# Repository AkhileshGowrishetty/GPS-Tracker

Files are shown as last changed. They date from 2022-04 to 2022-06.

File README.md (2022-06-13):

# GPS Tracker Project

A GPS Tracker Prototype used for locating tracking vehicles.

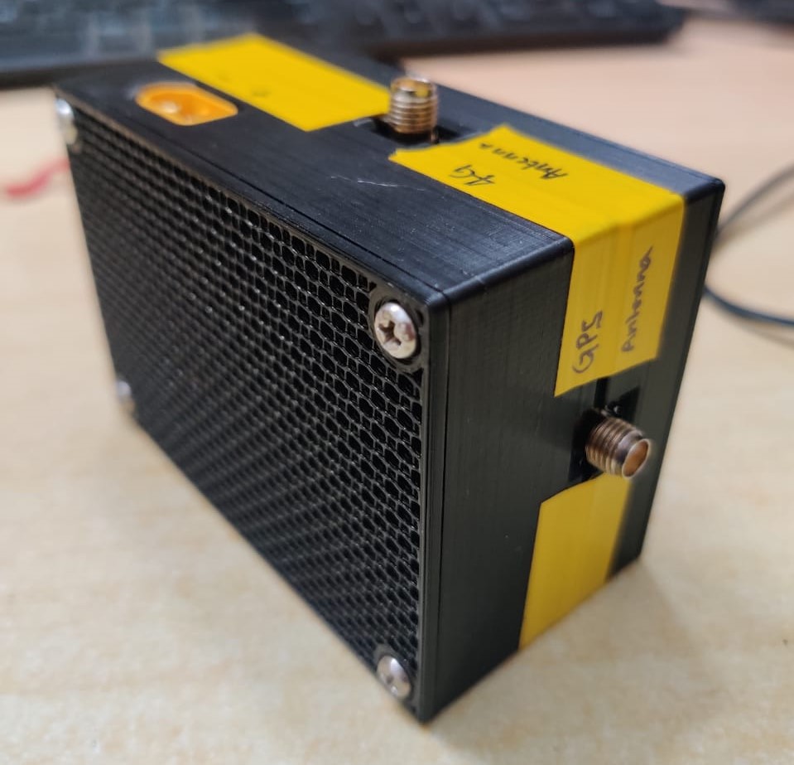
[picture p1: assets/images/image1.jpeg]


**Hardware:**
1. ESP32
1. SIM7600EI

The SIM7600 module used in this project can be at rhydoLABZ. The PCB and 3D designed enclosure are specific to this module.

This tracker gets the current location coordinates using the SIM7600 module, and then sends them to AWS. A web site is hosted on AWS to display the coordinates from the tracker.

AWS IoT Core, DynamoDB and EC2 services from AWS are used for this project.

---

### Instructions:
- The file `secrets_template.h` has the variables that has to be edited. After editing, rename the file to `secrets.h` and place it in the same folder that has the `main.cpp` file.
    ```
    The folder structure has to be some thing like this:
    -- Project
        | -- 
        | -- 
        | -- src
            | -- secrets.h
            | -- main.cpp
            | -- SIM7600.cpp
            | -- SIM7600.h
        | -- 
    ```

- Follow the steps in [Documentation for AWS](./Documentation/AWS_IoT_Core_Documentation.md) and [Documentation for SIM7600](./Documentation/Setting_Up_SIM7600.md).
    > For deeper understanding of the AT Commands, the document "SIM7500_SIM7600 Series_ AT Command Manual" can be referred.

- This project was developed in [PlatformIO](https://platformio.org/). There are many tutorials which help in installing and uploading the program to the ESP32.

---
### Understanding the code:
- The code creates few tasks to control various peripherals. 
    1. LED control
    1. Battery monitoring system
    1. Active time management
    1. Fetch GPS co-ordinates and Publish to AWS
    1. Monitoring the Serial input. (Work in progress)

- A semaphore is used to control the number of the times the status LED blinks. Few FreeRTOS functions to handle tasks are used to suspend and resume the LED control task.

- To prevent the battery from discharging through the voltage divider used for voltage level detection, a MOSFET is used to enable the voltage divider. This task also switched OFF the SIM7600 module if the voltage is low.

---
### Troubleshooting:
- To disable MQTT functions, the line `#define MQTT_CONNECT` can be commented. By commenting it, the AT commands corresponding to MQTT connection, publishing are not sent to SIM7600 module.

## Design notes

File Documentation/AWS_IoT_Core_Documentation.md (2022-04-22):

# AWS IoT Core Wiki

Documentation for the AWS IoT implemetation in Tracker project.

> References:  
> 1. [AWS Compute Blog - Building an AWS IoT Core device using AWS Serverless and an ESP32](https://aws.amazon.com/blogs/compute/building-an-aws-iot-core-device-using-aws-serverless-and-an-esp32/)
> 1. [AWS Docs - Tutorial: Storing device data in a DynamoDB table](https://docs.aws.amazon.com/iot/latest/developerguide/iot-ddb-rule.html)
---

**Table of Contents**

1. [Setting up IoT Core](#1-setting-up-iot-core)
    1. Registering a New Thing
    1. Creating a Policy
    1. Attaching the Policy
1. [Setting up Rule to insert received Data to DynamoDB](#2-setting-up-rule-to-insert-received-data-to-dynamodb)
    1. Creating a New Rule and Setting up Actions in the Rule

---

## 1. Setting up IoT Core
1. Registering a New Thing:  
    -  In the AWS Console, a Thing has to be registered before connecting to the MQTT broker. Firstly, we have to create in New Thing. Choose 'Things' in the console and choose **Register a New Thing**. Create a single thing.  
    - The thing can be named anything. The remaining fields can be left empty. Click on **Next**.  
    - Choose **Create Certificate**. Make sure to Download the *thing cert*, *private key* and *Amazon Root CA1* certificates. Save them somewhere secure. They will be needed to connect to the AWS IoT.
        > In this project, these certificates are sent to SIM7600 Module. The instructions can be found [here](./Setting_Up_SIM7600.md#2-download-certificates).
    - Click on **Activate**, **Attach a policy**.  
        > A policy is an object in AWS that, when associated with an identity or resource, defines their permissions. - [AWS Docs](https://docs.aws.amazon.com/IAM/latest/UserGuide/access_policies.html)
    - Skip adding a policy as of now. 
    - Choose **Register Thing**.

1. Creating a Policy:
    - In the AWS Console, choose **Secure, Policies, Create a policy**.
    - Name the policy. Choose the **Advanced** tab.
    - The following policy template can be pasted. In the template, replace the following:
        - **REGION:ACCOUNT_ID** with your **AWS region** and **AWS Account ID**.    
        - **ThingName** with the name of the Thing that was registered in previous step.
        - **SubTopic** with the topic which the Thing can subscribe.
        - **PubTopic** with the topic which the Thing can publish to.  
        ```json
        {
            "Version": "2012-10-17",
            "Statement": [
                {
                "Effect": "Allow",
                "Action": "iot:Connect",
                "Resource": "arn:aws:iot:REGION:ACCOUNT_ID:client/ThingName"
                },
                {
                "Effect": "Allow",
                "Action": "iot:Subscribe",
                "Resource": "arn:aws:iot:REGION:ACCOUNT_ID:topicfilter/SubTopic"
                },
                {
                "Effect": "Allow",
                "Action": "iot:Receive",
                "Resource": "arn:aws:iot:REGION:ACCOUNT_ID:topic/SubTopic"
                },
                {
                "Effect": "Allow",
                "Action": "iot:Publish",
                "Resource": "arn:aws:iot:REGION:ACCOUNT_ID:topic/PubTopic"
                }
            ]
        }
        ```
    - Choose **Create**.

1. Attaching the Policy:
    - In the AWS Console, choose **Secure, Certification**.
    - Select the one that was created for the registered device and choose **Actions, Attach Policy**.
    - Choose the previously created policy and click on **Attach**.

---

## 2. Setting up Rule to insert received Data to DynamoDB
Prior to Rule creation, a Table in DynamoDB must be created. It will have a primary key, sort key and data as columns. For this example, it is expected that a Table has a primary key of *Number* type and sort key of *String* type. The primary key will store the **Timestamp** and the sort key will store the **Topic** of the MQTT message.  
### Creating a New Rule and Setting up Actions in the Rule:  
- In the AWS Console, choose **Act, Rules**.
    - Click on **Create**.
    - In the top part of **Create a rule**:
        - In **Name**, enter the rule's name.
        - The rule can be described in the **Description**.
    - In the **Rule query statement** of **Create a rule**:
        - Select `2016-03-23` in **Using SQL version**.
        - In the **Rule query statement** edit box, paste the following. The statement implies that all the data from the topic to which data is published (**PubTopic**) is selected.
            ```sql
            SELECT * FROM "PubTopic"
            ```
    - In **Set one or more actions**:
        - Choose **Add action**, to open a list of rule actions.
        - In **Select an action**, choose **Insert a message into a DynamoDB table**.
        - Choose **Configure action** to open the selected action's configuration page.
    - In **Configure action**:
        - Choose the name of the DynamoDB Table to use in **Table Name**.
        - In **Partition key value**, enter `${timestamp()}`.
        - In **Sort key value**, enter `${topic()}`.
        - In **Write message data to this column**, enter `device_data`. This will create the `device_data` column in the DynamoDB Table.
        - The **Operation** field can be left blank.
        - In **Choose or create a role to grant AWS IoT access to perform this action**, choose **Create Role** if a new role has to be created or choose and existing role with the policies that allows to put an item in DynamoDB Tables.
        - In **Create a new role** enter the name of the role, and choose **Create role**.
        - Choose **Add action** at the bottom of **Configure action**.
        - Choose **Create rule** at the bottom of **Create a rule** to create the rule.

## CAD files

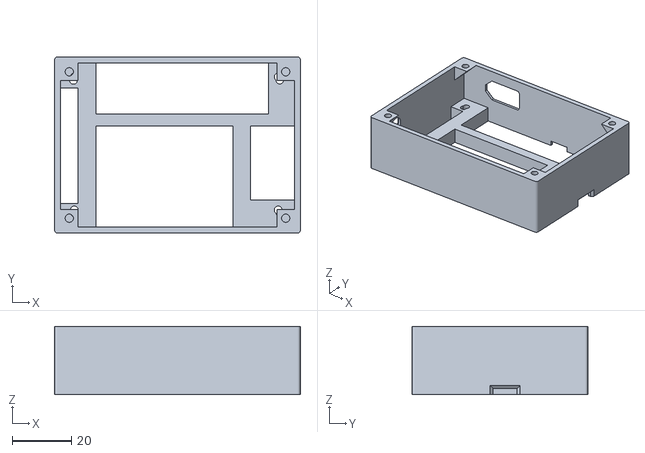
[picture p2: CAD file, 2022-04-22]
Enclosure/Holder_PCB.stl
83.0 x 59.4 x 23.0

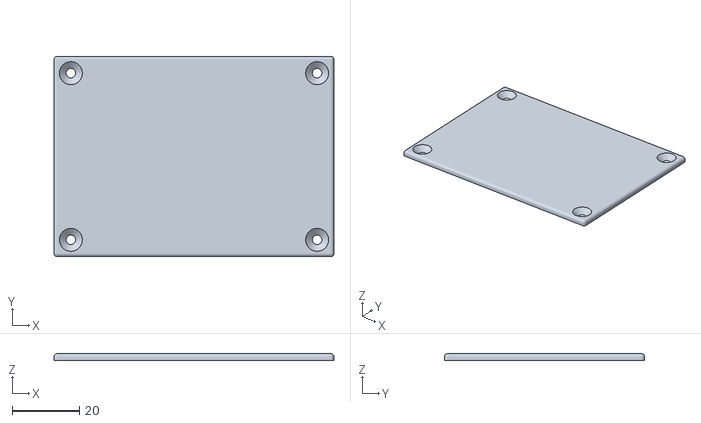
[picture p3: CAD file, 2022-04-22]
Enclosure/Cover_PCB.stl
83.0 x 59.4 x 2.00

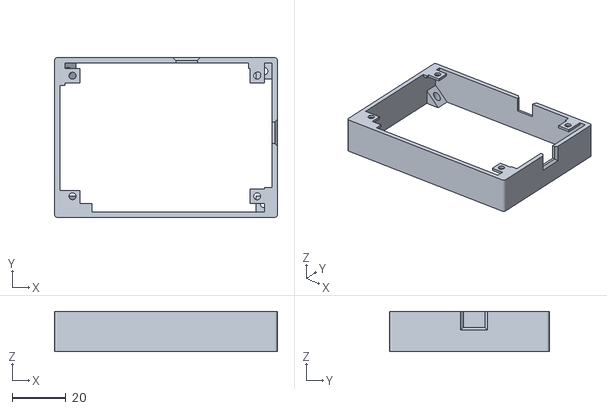
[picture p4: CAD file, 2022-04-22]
Enclosure/Holder_SIM7600.stl
83.0 x 59.4 x 15.0

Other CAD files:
Enclosure/Cover_SIM7600.stl

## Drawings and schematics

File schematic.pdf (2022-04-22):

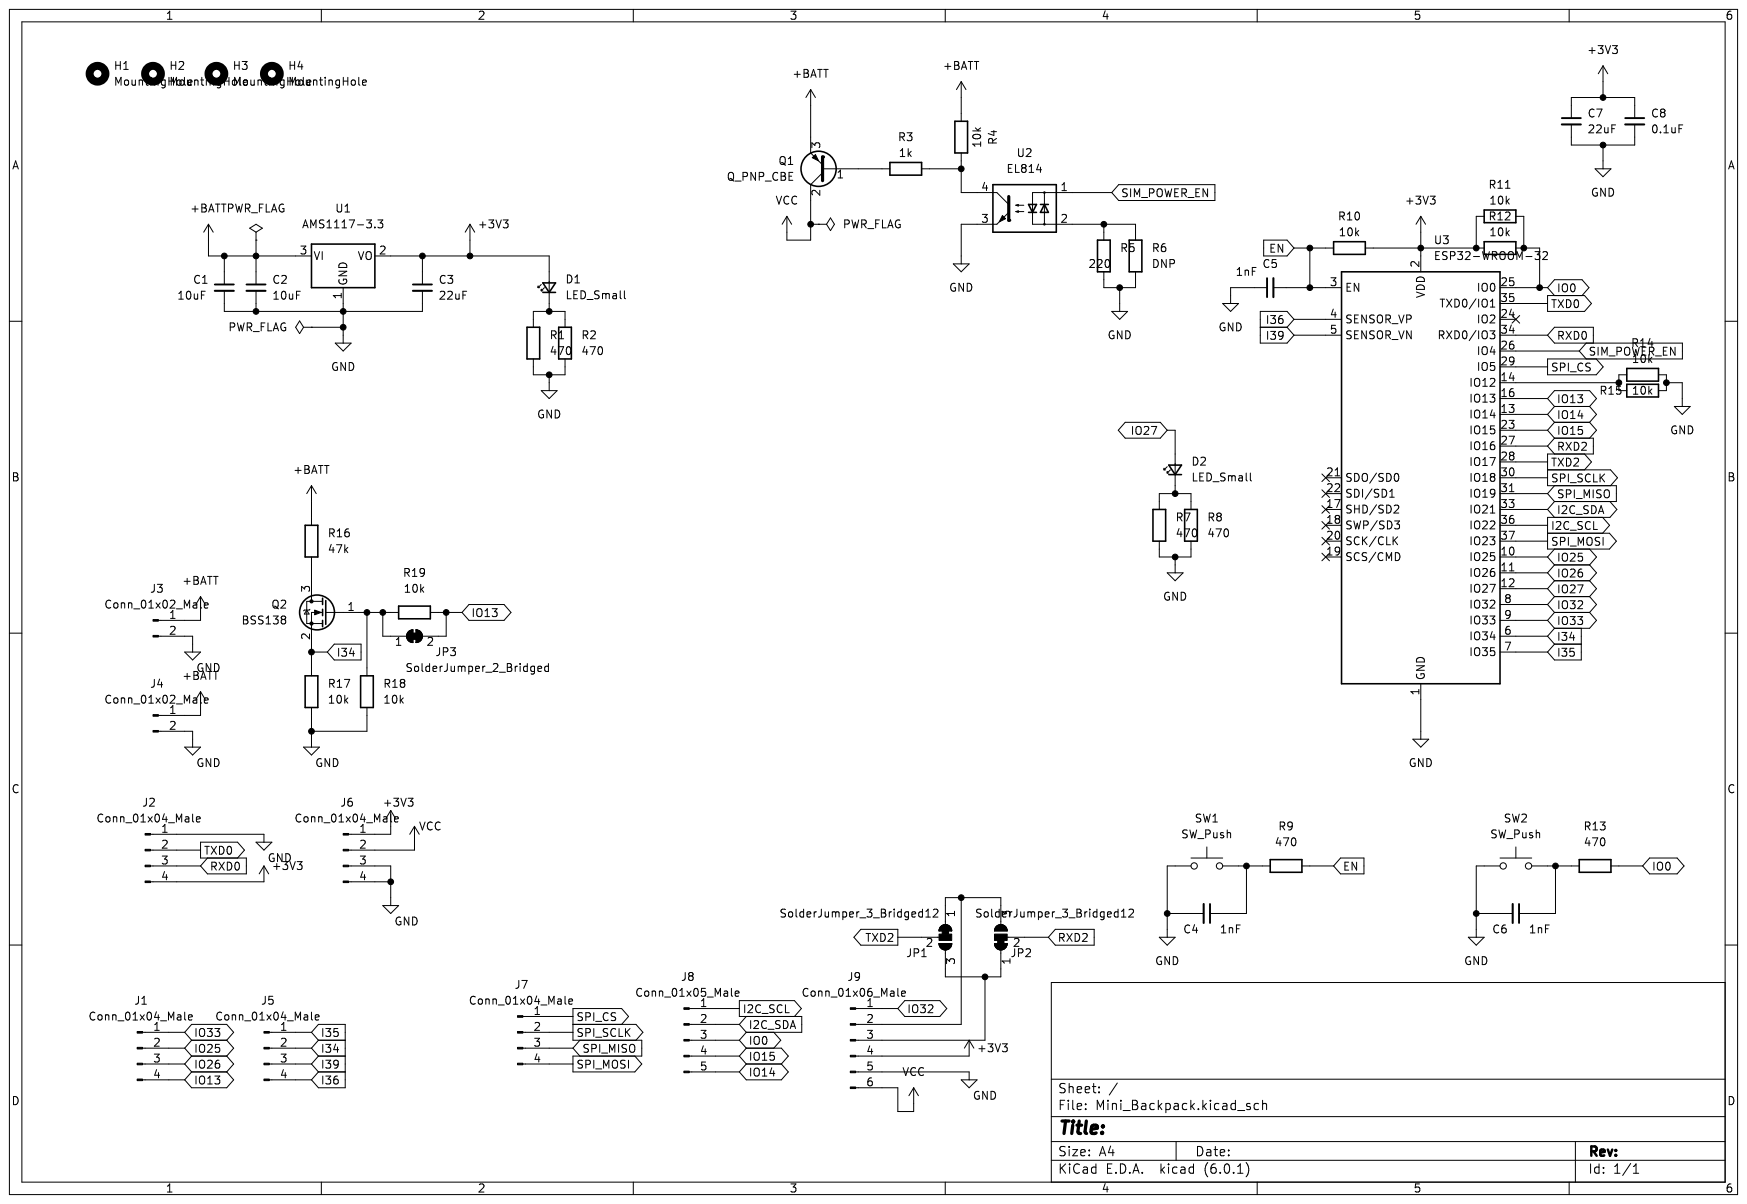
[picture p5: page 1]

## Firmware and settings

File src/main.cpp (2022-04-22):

#include <Arduino.h>
#include "SIM7600.h"
#include "secrets.h"
#include "functions.h"


void setup()
{
	Serial.begin(115200);
	Serial2.begin(115200);

	xSemaphoreGive(Semaphore_LED_blink_count);

	xTaskCreatePinnedToCore(blink_LED, "LED Blink", 2048, NULL, 1, &Task_LED_Control, 1);
	xTaskCreatePinnedToCore(battery_monitor, "Battery Monitoring Function", 2048, NULL, 1, &Task_Battery_Monitor, 1);
	
	
	
	delay(10000);
	sim7600.waitForResponse("PB DONE", 25);

	sim7600.echoOFF() ? ESP_LOGI(SIM7600_TAG, "Echo switched OFF") : ESP_LOGE(SIM7600_TAG, "Echo did not switch OFF");

	configureSSL_MQTT();

	gps.begin();

	xTaskCreatePinnedToCore(update_active_hours, "Real Time Management", 2048, NULL, 1, &Task_Clock, 1);
	xTaskCreatePinnedToCore(fetchGPS_pubMQTT, "Fetch GPS and Publish MQTT", 4096, NULL, 1, &Task_fetchGPS_pubMQTT, 1);
	//xTaskCreatePinnedToCore(serial_monitor, "Monitor Output from SIM7600", 4096, NULL, 1, &Task_Serial, 1);
}

void loop()
{

}

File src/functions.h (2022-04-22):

#ifndef FUNCTIONS_H
#define FUNCTIONS_H

#include "Arduino.h"
#include "SIM7600.h"
#include "driver/adc.h"
#include "esp_adc_cal.h"
#include "secrets.h"

#define MQTT_CONNECT
#define DEVICE_TAG "GPS Tracker Prototype"
#define SIM7600_TAG "SIM7600"
#define SSL_TAG "SSL"
#define MQTT_TAG "MQTT"

SIM7600 sim7600(Serial2);
GPS gps(Serial2);
MQTT mqtt(Serial2);
SSL ssl(Serial2);

TaskHandle_t Task_fetchGPS_pubMQTT;

TaskHandle_t Task_LED_Control;

TaskHandle_t Task_Battery_Monitor;

TaskHandle_t Task_Serial;

TaskHandle_t Task_Clock;

SemaphoreHandle_t Semaphore_LED_blink_count = xSemaphoreCreateBinary();

gpio_num_t LED = GPIO_NUM_27;
gpio_num_t BATTERY_MONITOR_EN = GPIO_NUM_13;

const double slope = 5.70;
const double BATT_min = 6.00;

const unsigned int AWS_update_interval_ms = 5000;

bool active_hours = true;
const unsigned int aws_port = 8883;
uint8_t LED_blink_count = 1;

/**
 * @brief Function to calculate the battery voltage using the voltage divider with MOSFET. 12-bit resolution.
 * 
 * 
 * @return double - Voltage of battery.
 */
double battery_voltage()
{
	gpio_set_level(BATTERY_MONITOR_EN, 1);
	vTaskDelay(50 / portTICK_PERIOD_MS);

	esp_adc_cal_characteristics_t adc_chars;

	esp_adc_cal_characterize(ADC_UNIT_1, ADC_ATTEN_DB_6, ADC_WIDTH_BIT_12, 1100, &adc_chars);

	uint32_t voltage;
	esp_adc_cal_get_voltage(ADC_CHANNEL_6, &adc_chars, &voltage);

	gpio_set_level(BATTERY_MONITOR_EN, 0);
	return (slope * (voltage / 1000.0) ) + 0.075;
}

/**
 * @brief Function to end the MQTT session.
 * 
 */
void endMQTT()
{
	#ifdef MQTT_CONNECT
	mqtt.disconnect() ? ESP_LOGI(MQTT_TAG, "MQTT broker disconnected") : ESP_LOGE(MQTT_TAG, "MQTT broker disconnection failed.");
	mqtt.releaseClient() ? ESP_LOGI(MQTT_TAG, "MQTT client released") : ESP_LOGE(MQTT_TAG, "MQTT client not released");
	mqtt.end() ? ESP_LOGI(MQTT_TAG, "MQTT session ended successfully") : ESP_LOGE(MQTT_TAG, "MQTT session did not end");
	#endif
}

/**
 * @brief Update the active_hours boolean based on the current time and active time.
 * 
 * @todo Implementation
 * 
 * @param parameter 
 */
void update_active_hours(void * parameter)
{
	while(true)
	{
		vTaskDelay(1000 / portTICK_PERIOD_MS);
	}
}

/**
 * @brief Task to monitor the battery voltage and switch ON/OFF the SIM module.
 * 
 * @param parameter 
 */
void battery_monitor(void * parameter)
{
	gpio_reset_pin(BATTERY_MONITOR_EN);
	gpio_set_direction(BATTERY_MONITOR_EN, GPIO_MODE_OUTPUT);

	adc_set_clk_div(1);
	adc1_config_width(ADC_WIDTH_BIT_12);
	adc1_config_channel_atten(ADC1_CHANNEL_6, ADC_ATTEN_DB_6);

	while(true)
	{
		if ( battery_voltage() < BATT_min + 0.3 || !active_hours)
		{
			vTaskSuspendAll();
			endMQTT();
			sim7600.shutdown();
			vTaskDelay(200 / portTICK_PERIOD_MS);
			sim7600.powerOFF();
			xSemaphoreTake(Semaphore_LED_blink_count, portMAX_DELAY);
			LED_blink_count = 3;
			xSemaphoreGive(Semaphore_LED_blink_count);

			while(true)
			{
				if ( !active_hours )
					vTaskResume(Task_LED_Control);
				vTaskDelay(2000 / portTICK_PERIOD_MS);
			}
		}
		else
		{
			sim7600.powerON();
		}
		vTaskDelay(5000 / portTICK_PERIOD_MS);
	}
}

/**
 * @brief Task to blink the LED based on the count.
 * 
 * @param parameter 
 */
void blink_LED(void *parameter)
{	
	gpio_reset_pin(LED);
	gpio_set_direction(LED, GPIO_MODE_OUTPUT);

	uint8_t blink_count;

	while (true)
	{
		gpio_set_level(LED, 0);
		vTaskSuspend(NULL);
		
		xSemaphoreTake(Semaphore_LED_blink_count, portMAX_DELAY);
		blink_count = LED_blink_count;
		xSemaphoreGive(Semaphore_LED_blink_count);

		for (uint8_t i = 0; i < blink_count; i++)
		{
			gpio_set_level(LED, 1);
			vTaskDelay(100 / portTICK_PERIOD_MS);
			gpio_set_level(LED, 0);
			vTaskDelay(100 / portTICK_PERIOD_MS);
		}
	}
}

/**
 * @brief Function to configure the SSL context and connect to the AWS MQTT broker.
 * 
 */
void configureSSL_MQTT()
{
	#ifdef MQTT_CONNECT
	ssl.checkCertificates(cacert, clientcert, clientkey) ? ESP_LOGI(SSL_TAG, "Certificates present") : ESP_LOGE(SSL_TAG, "Certificates not found");
	ssl.configureSSL(cacert, clientcert, clientkey) ? ESP_LOGI(SSL_TAG, "SSL configured successfully") : ESP_LOGE(SSL_TAG, "SSL configuration failed");

	mqtt.begin() ? ESP_LOGI(MQTT_TAG, "MQTT session started successfully") : ESP_LOGE(MQTT_TAG, "MQTT session did not start");
	mqtt.acquireClient() ? ESP_LOGI(MQTT_TAG, "MQTT client acquired successfully") : ESP_LOGE(MQTT_TAG, "MQTT client was not acquired");
	mqtt.setSSLContext() ? ESP_LOGI(MQTT_TAG, "MQTT SSL context set successfully") : ESP_LOGE(MQTT_TAG, "MQTT SSL context was not set");
	mqtt.disconnect();
	bool success = mqtt.connect(aws_server, aws_port) ? ESP_LOGI(MQTT_TAG, "MQTT broker connected successfully") : ESP_LOGE(MQTT_TAG, "Could not connect to MQTT broker");

	xSemaphoreTake(Semaphore_LED_blink_count, portMAX_DELAY);
	LED_blink_count = success ? 1 : 3;
	const unsigned int delay_interval = success ? 300 : 1000;
	xSemaphoreGive(Semaphore_LED_blink_count);

	vTaskResume(Task_LED_Control);
	vTaskDelay(delay_interval / portTICK_PERIOD_MS);
	#endif
}

/**
 * @brief Task to Fetch GPS data and Publish MQTT message
 * 
 * @param parameter 
 */
void fetchGPS_pubMQTT(void *parameter)
{
	Serial.println("Latitude\tLongitude\tAltitude\tSpeed\t\tCourse\t\tEpoch Time");

	while (true)
	{
		if ( gps.getData() )
		{
			Serial.printf("Latitude:\t%lf\nLongitude:\t%lf\n", gps.data.latitude, gps.data.longitude);
			Serial.printf("Altitude:\t%lf\nSpeed:\t\t%lf\n", gps.data.altitude, gps.data.speed);
			Serial.printf("Course:\t\t%lf\nEpoch Time:\t%ld\n", gps.data.course, gps.data.timestamp);

			uint8_t mac[6];
			esp_read_mac(mac, ESP_MAC_WIFI_STA);

			char publishTopic[20];

			sprintf(publishTopic, "sim7600/pub");

			char payload[150];
			snprintf(payload, sizeof(payload), "{\"latitude\":%.8lf,\"longitude\":%.8lf,\"speed\":%.2lf,\"course\":%.2lf,\"timestamp\":%li,\"battery\":%.2lf}",
					 gps.data.latitude, gps.data.longitude, gps.data.speed, gps.data.course, gps.data.timestamp, battery_voltage());

			Serial.printf("%u-%s\n", strlen(publishTopic), publishTopic);
			Serial.printf("%u-%s\n", strlen(payload), payload);
			#ifdef MQTT_CONNECT
			mqtt.setPublishTopicPayload(publishTopic, payload);
			bool success = mqtt.publish();

			xSemaphoreTake(Semaphore_LED_blink_count, portMAX_DELAY);
			LED_blink_count = success ? 1 : 3;
			const unsigned int delay_interval = success ? 300 : 1000;
			xSemaphoreGive(Semaphore_LED_blink_count);

			vTaskResume(Task_LED_Control);
			vTaskDelay(delay_interval / portTICK_PERIOD_MS);
			#endif
		}
		else
		{
			xSemaphoreTake(Semaphore_LED_blink_count, portMAX_DELAY);
			LED_blink_count = 2;
			const unsigned int delay_interval = 650;
			xSemaphoreGive(Semaphore_LED_blink_count);

			vTaskResume(Task_LED_Control);
			vTaskDelay(delay_interval / portTICK_PERIOD_MS);
			Serial.println("Invalid Data or Module is not Switched ON or MQTT disabled\n");
		}

		vTaskDelay(AWS_update_interval_ms / portTICK_PERIOD_MS);
	}
}
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
